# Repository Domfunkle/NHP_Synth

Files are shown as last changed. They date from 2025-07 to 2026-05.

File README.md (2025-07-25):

# NHP_Synth: ESP32 Dual DDS Synthesizer

This project implements a dual-channel Direct Digital Synthesis (DDS) signal generator on the ESP32 platform. It features:

- Two independent sine wave outputs (via DACs on GPIO25 and GPIO26)
- Precise square wave output (GPIO18) synchronized to DDS phase
- UART command interface for real-time control
- Phase, frequency, and amplitude control for each channel
- Odd harmonic mixing with amplitude and phase control per channel (total 8 simultaneous harmonics across both channels)
- External sync input (GPIO19, rising edge)
- High-resolution timer for accurate waveform generation

## Features
- **Frequency Range:** 20 Hz to 8 kHz (configurable)
- **Amplitude Ramping:** Smooth amplitude changes to prevent clicks
- **Phase Control:** Set phase offset for each channel
- **Harmonic Mixing:** Add odd harmonics (3rd, 5th, 7th, etc) to either channel, with amplitude and phase control. Up to a total of 8 harmonics can be active across both channels at once.
- **UART Commands:**
  - `wf[a|b]<freq>`: Set channel A or B frequency (Hz)
  - `wp[a|b]<deg>`: Set channel A or B phase (degrees, -180 to +180)
  - `wa[a|b]<ampl>`: Set channel A or B amplitude (0-100)
  - `wh[a|b]<order>,<pct>[,<phase>]`: Mix odd harmonic to channel A or B (e.g. `wha3,10` for 10% 3rd harmonic, or `wha7,20,-90` for 20% 7th harmonic at -90° phase)
  - `whcl[a|b]`: Clear all harmonics for channel A or B
  - `help`: Show help message

## Hardware Connections
- **DAC Channel A:** GPIO25
- **DAC Channel B:** GPIO26
- **Square Wave Output:** GPIO18
- **Sync Input:** GPIO19 (rising edge, with pulldown)

## Project Structure

```
NHP_Synth/
├── firmware/           # ESP32 firmware (ESP-IDF project)
│   ├── main/          # Main application source
│   ├── .devcontainer/ # ESP-IDF development container
│   └── .vscode/       # ESP32-specific VS Code settings
├── host/              # Python host control interface
│   ├── synth_control/ # Python control library
│   ├── examples/      # Usage examples
│   ├── .devcontainer/ # Python development container
│   └── .vscode/       # Python-specific VS Code settings
├── tools/             # Shared utilities and scripts
└── .vscode/           # Root workspace configuration
```

## Build & Flash

### Firmware (ESP32)
Navigate to the firmware directory and use ESP-IDF:

```bash
cd firmware
idf.py build
idf.py -p /dev/ttyUSB0 flash
```

Or use the convenient script for multiple devices:

```bash
./tools/flash_multiple.sh
```

## Host Control (Python)

A Python interface is provided for programmatic control:

```bash
cd host
python3 -m venv .venv
source .venv/bin/activate
pip install -r requirements.txt

# Run examples
python examples/basic_control.py
python examples/harmonic_sweep.py
```

## UART Usage
Connect to the ESP32 UART (default 115200 baud) and type commands as described above. Type `help` for a list of commands.

## Linux commands to test UART
```bash
# Generate a square wave on Channel A at 50Hz
printf "wha3,33\r" > /dev/ttyUSB1
printf "wha5,20\r" > /dev/ttyUSB1
printf "wha7,14\r" > /dev/ttyUSB1
printf "wha9,11\r" > /dev/ttyUSB1
printf "wha11,9\r" > /dev/ttyUSB1
printf "wha13,8\r" > /dev/ttyUSB1
printf "wha15,7\r" > /dev/ttyUSB1
printf "wha17,6\r" > /dev/ttyUSB1
```

```bash
# Clear all harmonics for Channel A and B
printf "whcla\r" > /dev/ttyUSB1
printf "whclb\r" > /dev/ttyUSB1
```

```bash
# Rolling harmonic phase for Channel A and B
ph=-180
while true; do
    printf "wha5,20,%d\n" "$ph" > /dev/ttyUSB1
    invph=$((ph * -1))
    printf "whb3,10,%d\n" "$invph" > /dev/ttyUSB1
    sleep 0.03
    ph=$((ph + 1))
    if [ "$ph" -gt 180 ]; then
        ph=-180
    fi
done
```

## Development

### VS Code Workspace
Open the multi-root workspace for unified development:
```bash
code .vscode/NHP_Synth.code-workspace
```

### DevContainers
Each component has its own development container:
- **Firmware**: ESP-IDF container with all tools
- **Host**: Python container with analysis libraries

### Tools
- `tools/flash_multiple.sh` - Flash firmware to multiple devices
- `tools/uart_test.py` - Test UART communication

## File Structure
- `firmware/main/main.c`: Main ESP32 application source
- `firmware/build/`: Build artifacts (ignored by git)
- `host/synth_control/`: Python control library
- `host/examples/`: Python usage examples
- `tools/`: Shared utilities and scripts
- `.gitignore`: Excludes build and config files from version control

## License
MIT License (or specify your license here)

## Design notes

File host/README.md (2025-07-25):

# NHP_Synth Host Control

Python interface for controlling the ESP32 NHP_Synth dual-channel DDS synthesizer.

## Installation

1. Create and activate a virtual environment:
```bash
python3 -m venv .venv
source .venv/bin/activate  # On Windows: .venv\Scripts\activate
```

2. Install dependencies:
```bash
pip install -r requirements.txt
```

3. Install the package in development mode:
```bash
pip install -e .
```

## Usage

### Basic Control

```python
from synth_control import SynthInterface

with SynthInterface('/dev/ttyUSB0') as synth:
    # Set frequency and amplitude
    synth.set_frequency('a', 440)  # Channel A to 440Hz
    synth.set_amplitude('a', 80)   # 80% amplitude
    
    # Add harmonics
    synth.add_harmonic('a', 3, 20)  # 3rd harmonic at 20%
    synth.add_harmonic('a', 5, 10)  # 5th harmonic at 10%
```

### Waveform Generation

```python
from synth_control import SynthInterface, WaveformGenerator

with SynthInterface('/dev/ttyUSB0') as synth:
    waveform_gen = WaveformGenerator(synth)
    
    # Generate square wave approximation
    waveform_gen.apply_waveform('a', 'square', 200, 70)
    
    # Frequency sweep
    waveform_gen.sweep_frequency('a', 100, 1000, 5)
```

## Examples

Run the example scripts:

```bash
# Basic control demo
python examples/basic_control.py

# Harmonic and waveform demonstrations
python examples/harmonic_sweep.py
```

## API Reference

### SynthInterface

- `set_frequency(channel, frequency)` - Set channel frequency (20-8000 Hz)
- `set_amplitude(channel, amplitude)` - Set channel amplitude (0-100%)
- `set_phase(channel, phase)` - Set channel phase (-180 to +180 degrees)
- `add_harmonic(channel, order, percent, phase=0)` - Add harmonic to channel
- `clear_harmonics(channel)` - Clear all harmonics from channel

### WaveformGenerator

- `apply_waveform(channel, type, frequency, amplitude)` - Apply predefined waveform
- `sweep_frequency(channel, start, end, duration)` - Perform frequency sweep
- `phase_sweep(channel, harmonic_order, duration)` - Sweep harmonic phase

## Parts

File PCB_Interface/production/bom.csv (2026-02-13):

Designator | Footprint | Quantity | Value | LCSC Part #
C1, C12, C2, C5, C6 | 0603 | 5 | 100n
C10, C9 | 0603 | 2 | 470p
C11, C13, C20, C21, C22, C24 | 0805 | 6 | 22u/16V
C14, C15 | 0603 | 2 | 22p
C16 | 0603 | 1 | 10n
C17 | 0603 | 1 | 4n7
C18, C23 | 0603 | 2 | 15p
C19 | 0603 | 1 | 220n
C3, C4 | 0603 | 2 | 10u
C7, C8 | 0603 | 2 | 1n
CN1 | CONN-TH_WJ15EDGRC-3.81-6P | 1 | WJ15EDGRC-3.81-6P | C7246
D1, D5 | SOD-123_L2.8-W1.8-LS3.7-RD | 2 | MBR120LSF | C130880
D3, D4 | SOD-123FL_L2.7-W1.8-LS3.8-BI | 2 | SMF9.0CA_C19077504 | C19077504
E1, E2 | SOD-323_L1.8-W1.3-LS2.5-RD | 2 | CESD3V3D3 | C38388
L1, L2 | IND-SMD_L5.4-W5.2_FXL0530 | 2 | 4u7 | C177246
LED1 | LED0805-R-RD | 1 | GREEN | C2297
LED2, LED3 | LED0805-R-RD | 2 | RED | C84256
Q1 | SOT-23_L2.9-W1.3-P1.90-LS2.4-BR | 1 | AO3401A | C15127
R1, R11, R12, R2, R22, R3, R4 | 0603 | 7 | 10k
R10, R7, R8, R9 | 0603 | 4 | 100k
R13, R14 | 0603 | 2 | 22k
R15 | 0603 | 1 | 100
R16, R24, R29, R5, R6 | 0603 | 5 | 47k
R17, R18, R19, R20 | 0603 | 4 | 330
R21 | 0603 | 1 | 560k
R23, R30 | 0603 | 2 | 4k7
R25 | 0603 | 1 | 59k
R26, R27 | RES-ADJ-SMD_TC33X-2-104E | 2 | 100k | C719186
R28 | 0603 | 1 | 750k
RV1, RV2 | RES-ADJ-TH_3296P | 2 | 100k | C780112
U10, U11 | HDR-TH_20P-P2.54-V-F | 2 | ZX-PM2.54-1-20PY | C7499336
U3, U4 | SOIC-14_L8.7-W3.9-P1.27-LS6.0-BL | 2 | LM324DT | C71035
U9 | QFN-24_L4.0-W4.0-P0.50-TL-EP2.6 | 1 | TPS65131RGER | C87663

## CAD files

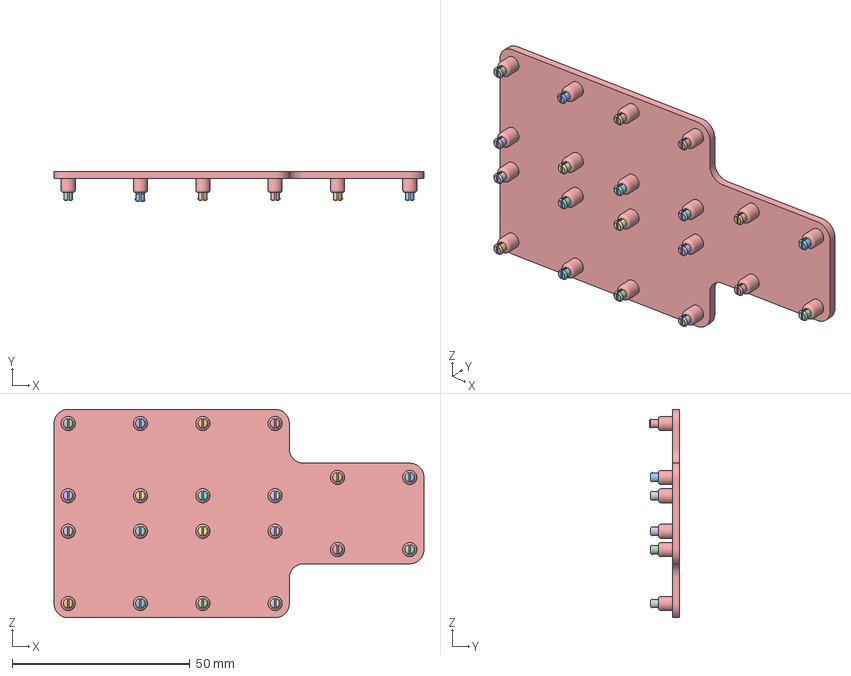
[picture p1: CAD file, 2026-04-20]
model/3-phase-synth-model-Encoder-Plate.3mf
104.1 x 8.50 x 58.6 mm

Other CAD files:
Drawing1.dwg
model/model.FCStd

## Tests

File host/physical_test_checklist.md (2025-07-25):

# NHP_Synth Physical Test Checklist

Use this checklist to verify hardware/software integration after any code changes:

## 1. Encoder Detection Test
- Power on and verify all rotary encoders are detected and initialized correctly.

## 2. Button Press Test
- Short press each encoder button and confirm mode switching (individual/all synths, channel cycling).
- Long press each encoder button and confirm reset to default values for amplitude, frequency, phase, and harmonics.

## 3. Encoder Rotation Test
- Rotate each encoder and verify amplitude, frequency, phase, and harmonics values change as expected.
- Check for correct value limits (e.g., amplitude 0–100%, frequency 20–70Hz, phase -360° to +360°).

## 4. LED Feedback Test
- Confirm LEDs respond to button presses and resets (e.g., flash white on reset, show correct color for each function).

## 5. Synth Output Test
- Measure output signals from each synth channel to verify amplitude, frequency, phase, and harmonics changes are reflected in the hardware.

## 6. State Persistence Test
- Power cycle the system and confirm synth state is saved and restored correctly.

## 7. Error Handling Test
- Disconnect one or more encoders and verify the system handles missing devices gracefully (no crash, correct status messages).

## 8. Multi-Synth Coordination Test
- Test “all synths” mode to ensure simultaneous updates across all devices.

## 9. Timeout Reversion Test
- Leave the system in “individual” mode and confirm it reverts to “all” mode after the timeout period.

## 10. Shutdown Test
- Trigger a clean shutdown and verify all synth outputs are set to zero.

---
Perform these tests after any code changes to ensure full functionality and hardware safety.

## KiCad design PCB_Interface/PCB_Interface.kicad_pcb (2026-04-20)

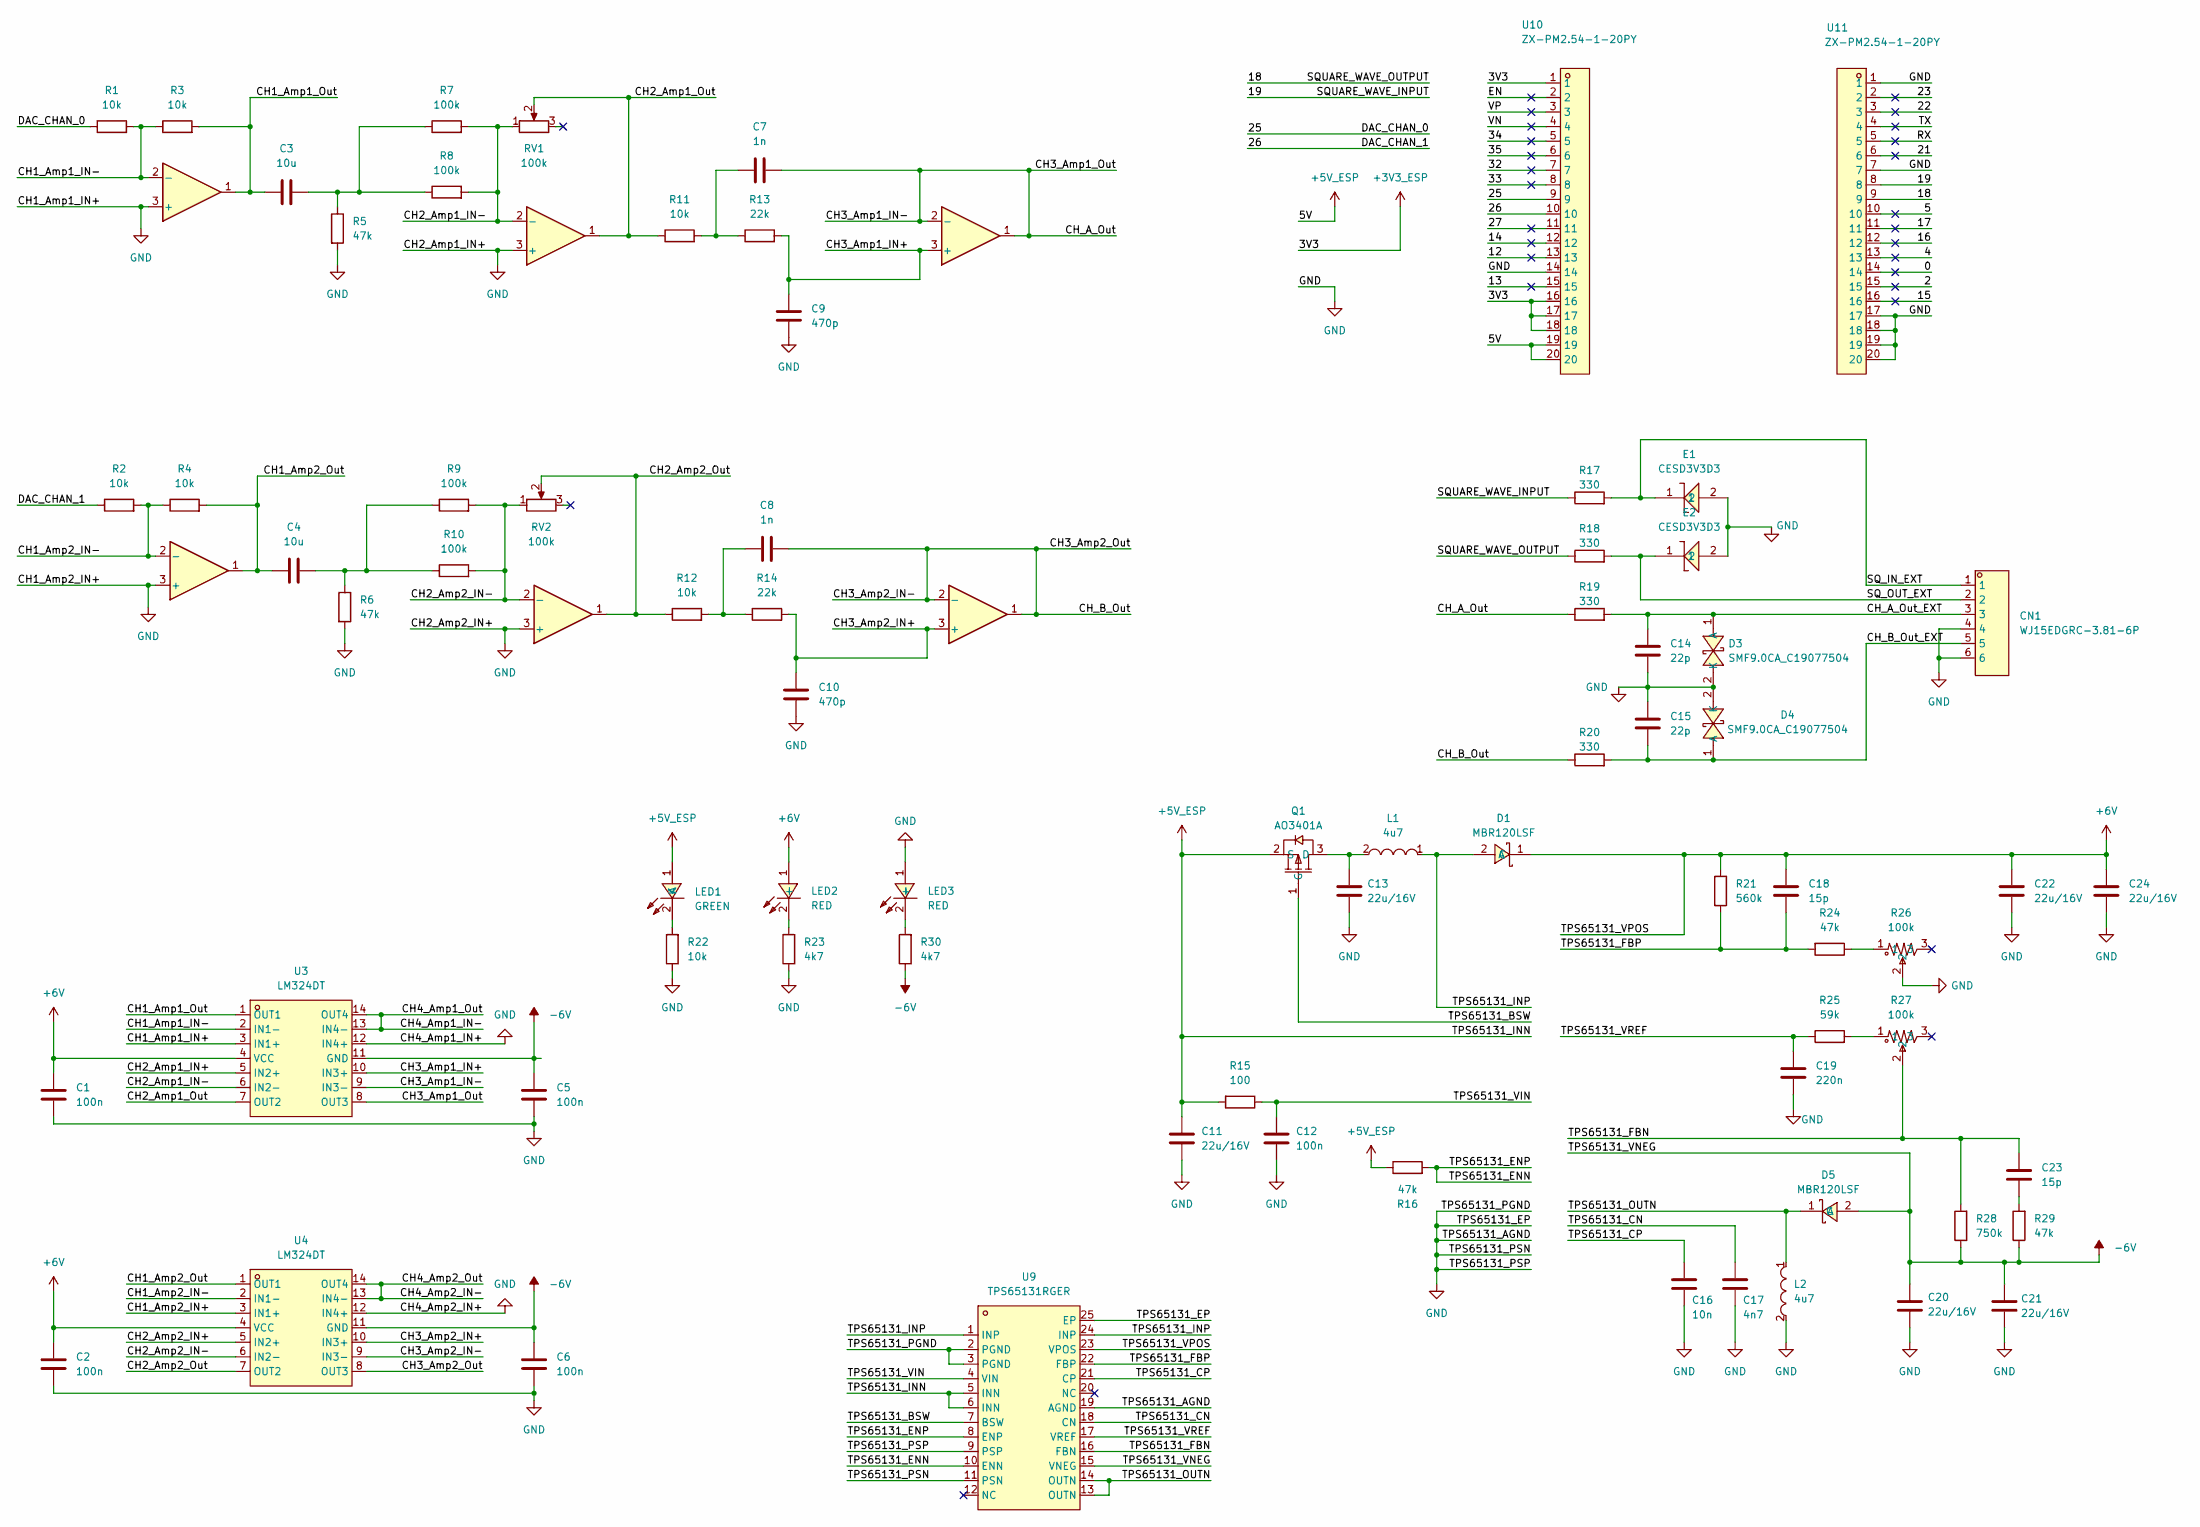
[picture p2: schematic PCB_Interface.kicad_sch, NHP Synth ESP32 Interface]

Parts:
C1, C2, C5, C6, C12: 100n; C_0603_1608Metric
C3, C4: 10u; C_0603_1608Metric
C7, C8: 1n; C_0603_1608Metric
C9, C10: 470p; C_0603_1608Metric
C11, C13, C20, C21, C22, C24: 22u/16V; C_0805_2012Metric
C14, C15: 22p; C_0603_1608Metric
C16: 10n; C_0603_1608Metric
C17: 4n7; C_0603_1608Metric
C18, C23: 15p; C_0603_1608Metric
C19: 220n; C_0603_1608Metric
CN1: WJ15EDGRC-3.81-6P; CONN-TH_WJ15EDGRC-3.81-6P; LCSC Part C7246
D1, D5: MBR120LSF; SOD-123_L2.8-W1.8-LS3.7-RD; LCSC Part C130880
D3, D4: SMF9.0CA_C19077504; SOD-123FL_L2.7-W1.8-LS3.8-BI; LCSC Part C19077504
E1, E2: CESD3V3D3; SOD-323_L1.8-W1.3-LS2.5-RD; LCSC Part C38388
L1, L2: 4u7; IND-SMD_L5.4-W5.2_FXL0530; LCSC Part C177246
LED1: GREEN; LED0805-R-RD; LCSC Part C2297
LED2, LED3: RED; LED0805-R-RD; LCSC Part C84256
Q1: AO3401A; SOT-23_L2.9-W1.3-P1.90-LS2.4-BR; LCSC Part C15127
R1, R2, R3, R4, R11, R12, R22: 10k; R_0603_1608Metric
R5, R6, R16, R24, R29: 47k; R_0603_1608Metric
R7, R8, R9, R10: 100k; R_0603_1608Metric
R13, R14: 22k; R_0603_1608Metric
R15: 100; R_0603_1608Metric
R17, R18, R19, R20: 330; R_0603_1608Metric
R21: 560k; R_0603_1608Metric
R23, R30: 4k7; R_0603_1608Metric
R25: 59k; R_0603_1608Metric
R26, R27: 100k; RES-ADJ-SMD_TC33X-2-104E; LCSC Part C719186
R28: 750k; R_0603_1608Metric
RV1, RV2: 100k; RES-ADJ-TH_3296P; LCSC Part C780112
U1, U2, U5, U6, U7, U8: LM324
U3, U4: LM324DT; SOIC-14_L8.7-W3.9-P1.27-LS6.0-BL; LCSC Part C71035
U9: TPS65131RGER; QFN-24_L4.0-W4.0-P0.50-TL-EP2.6; LCSC Part C87663
U10, U11: ZX-PM2.54-1-20PY; HDR-TH_20P-P2.54-V-F; LCSC Part C7499336

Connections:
+3V3_ESP: U10.1, U10.16, U10.17, U10.18
+5V_ESP: C11.1, LED1.1 (A), Q1.2 (S), R15.2, R16.1, U9.5 (INN), U9.6 (INN), U10.19, U10.20
+6V: C1.2, C2.2, C18.1, C22.1, C24.1, D1.1 (C), LED2.1 (+), R21.2, U3.4 (VCC), U4.4 (VCC), U9.23 (VPOS)
-6V: C5.2, C6.2, C20.1, C21.1, D5.2 (A), R28.1, R29.1, R30.1, U3.11 (GND), U4.11 (GND), U9.15 (VNEG)
/0: U11.14
/2: U11.15
/4: U11.13
/5: U11.10
/12: U10.13
/13: U10.15
/14: U10.12
/15: U11.16
/16: U11.12
/17: U11.11
/18: R18.1, U11.9
/19: R17.1, U11.8
/21: U11.6
/22: U11.3
/23: U11.2
/25: R1.1, U10.9
/26: R2.1, U10.10
/27: U10.11
/32: U10.7
/33: U10.8
/34: U10.5
/35: U10.6
/CH1_Amp1_IN-: R1.2, R3.1, U1.2 (-), U3.2 (IN1-)
/CH1_Amp1_Out: C3.1, R3.2, U1.1, U3.1 (OUT1)
/CH1_Amp2_IN-: R2.2, R4.1, U2.2 (-), U4.2 (IN1-)
/CH1_Amp2_Out: C4.1, R4.2, U2.1, U4.1 (OUT1)
/CH2_Amp1_IN-: R7.2, R8.2, RV1.1, U3.6 (IN2-), U5.2 (-)
/CH2_Amp1_Out: R11.1, RV1.2, U3.7 (OUT2), U5.1
/CH2_Amp2_IN-: R9.2, R10.2, RV2.1, U4.6 (IN2-), U6.2 (-)
/CH2_Amp2_Out: R12.1, RV2.2, U4.7 (OUT2), U6.1
/CH3_Amp1_IN+: C9.2, R13.2, U3.10 (IN3+), U7.3 (+)
/CH3_Amp1_IN-: C7.2, R19.1, U3.8 (OUT3), U3.9 (IN3-), U7.1, U7.2 (-)
/CH3_Amp2_IN+: C10.2, R14.2, U4.10 (IN3+), U8.3 (+)
/CH3_Amp2_IN-: C8.2, R20.1, U4.8 (OUT3), U4.9 (IN3-), U8.1, U8.2 (-)
/CH4_Amp1_IN-: U3.13 (IN4-), U3.14 (OUT4)
/CH4_Amp2_IN-: U4.13 (IN4-), U4.14 (OUT4)
/CH_A_Out_EXT: C14.1, CN1.3, D3.1 (A), R19.2
/CH_B_Out_EXT: C15.2, CN1.5, D4.1 (A), R20.2
/EN: U10.2
/RX: U11.5
/SQ_IN_EXT: CN1.1, E1.1, R17.2
/SQ_OUT_EXT: CN1.2, E2.1, R18.2
/TPS65131_BSW: Q1.1 (G), U9.7 (BSW)
/TPS65131_CN: C17.1, U9.18 (CN)
/TPS65131_CP: C16.1, U9.21 (CP)
/TPS65131_ENN: R16.2, U9.8 (ENP), U9.10 (ENN)
/TPS65131_FBN: C23.1, R27.2, R28.2, U9.16 (FBN)
/TPS65131_FBP: C18.2, R21.1, R24.2, U9.22 (FBP)
/TPS65131_INP: D1.2 (A), L1.1, U9.1 (INP), U9.24 (INP)
/TPS65131_OUTN: D5.1 (C), L2.1, U9.13 (OUTN), U9.14 (OUTN)
/TPS65131_VIN: C12.1, R15.1, U9.4 (VIN)
/TPS65131_VREF: C19.1, R25.1, U9.17 (VREF)
/TX: U11.4
/VN: U10.4
/VP: U10.3
GND: C1.1, C2.1, C5.1, C6.1, C9.1, C10.1, C11.2, C12.2, C13.2, C14.2, C15.1, C16.2, C17.2, C19.2, C20.2, C21.2, C22.2, C24.2, CN1.4, CN1.6, D3.2 (K), D4.2 (K), E1.2, E2.2, L2.2, LED3.1 (+), R5.2, R6.2, R22.1, R23.1, R26.2, U1.3 (+), U2.3 (+), U3.3 (IN1+), U3.5 (IN2+), U3.12 (IN4+), U4.3 (IN1+), U4.5 (IN2+), U4.12 (IN4+), U5.3 (+), U6.3 (+), U9.2 (PGND), U9.3 (PGND), U9.9 (PSP), U9.11 (PSN), U9.19 (AGND), U9.25 (EP), U10.14, U11.1, U11.7, U11.17, U11.18, U11.19, U11.20
unnamed: C3.2, R5.1, R7.1, R8.1
unnamed: C4.2, R6.1, R9.1, R10.1
unnamed: C7.1, R11.2, R13.1
unnamed: C8.1, R12.2, R14.1
unnamed: C23.2, R29.2
unnamed: LED1.2 (K), R22.2
unnamed: LED2.2 (-), R23.2
unnamed: LED3.2 (-), R30.2
unnamed: C13.1, L1.2, Q1.3 (D)
unnamed: R24.1, R26.1
unnamed: R25.2, R27.1

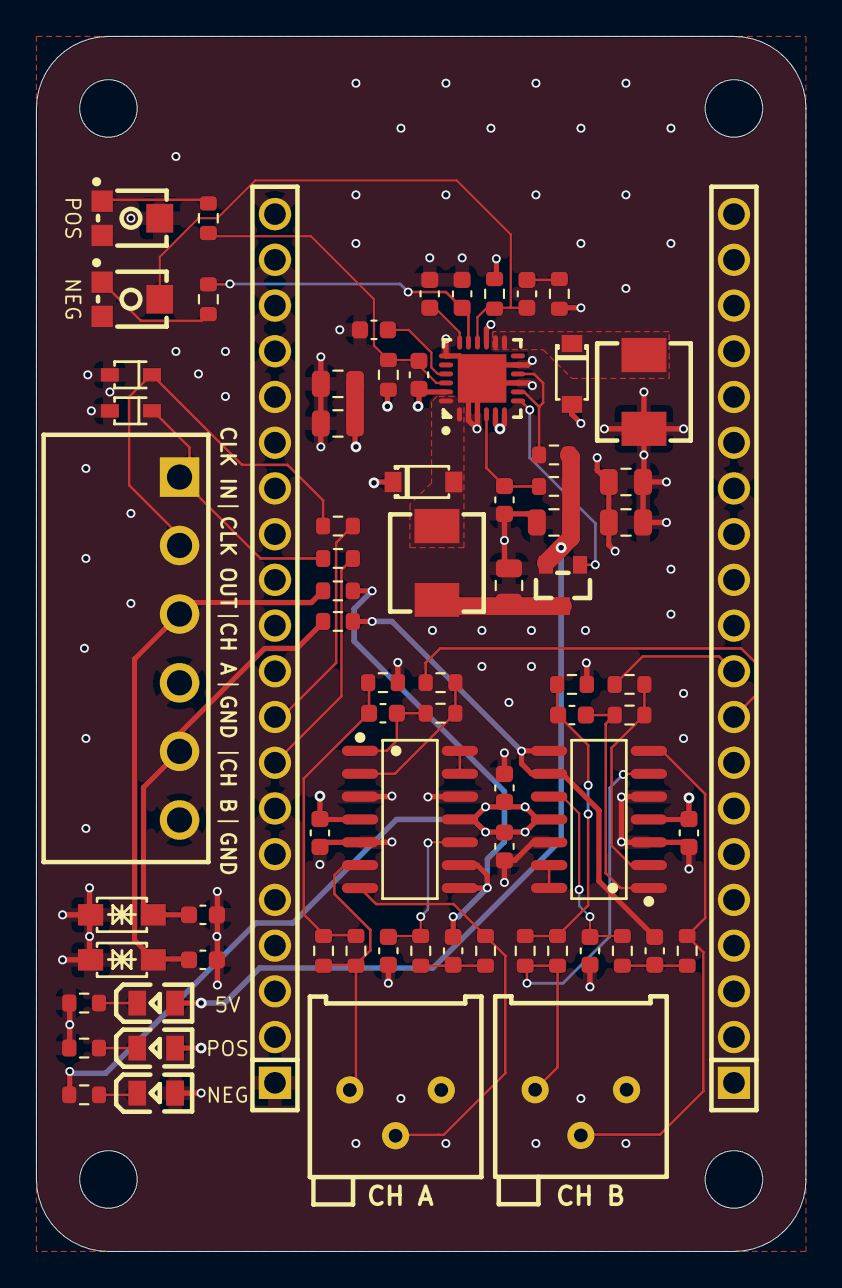
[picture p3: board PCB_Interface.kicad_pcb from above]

Board: 4 copper layers, 42.8 x 67.5 mm, 74 parts (0 on the bottom side), 48 nets.

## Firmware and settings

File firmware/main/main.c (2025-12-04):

// Includes
#include <stdio.h>
#include <math.h>
#include <string.h>
#include "freertos/FreeRTOS.h"
#include "freertos/task.h"
#include "esp_log.h"
#include "esp_timer.h"
#include "driver/uart.h"
#include "driver/gpio.h"
#include "esp_task_wdt.h"
#include "driver/dac_oneshot.h"

// Macros and Constants
#define TABLE_SIZE (1 << 16)
#define MIN_FREQ 20
#define MAX_FREQ 8000
#define UART_NUM UART_NUM_0
#define UART_RX_BUF_SIZE 256
#define SQUARE_WAVE_OUTPUT 18  // GPIO for square wave output
#define SQUARE_WAVE_INPUT 19
#define SQUARE_WAVE_HZ 50
#define PERIOD_US 50         // period in microseconds for DDS output
#define AMPL_RAMP_STEP 1e-3 // Adjust for ramp speed (smaller = slower)
#define MAX_HARMONICS 8 // Maximum harmonics across both channels
#define PHASE_SCALE (int)(TABLE_SIZE / (2.0 * M_PI))
#define M_PI_180 (M_PI / 180.0f)

// Per-channel harmonics (arrays for multiple harmonics)
typedef struct {
    int order;
    float percent; // 0-100
    float phase;   // radians
    int phase_offset_int; // cached phase offset for DDS
} harmonic_t;

static volatile harmonic_t harmonics[2][MAX_HARMONICS] = {{{0}}};

// Static Variables
static const char *TAG = "dac_oneshot_test";
static uint8_t waveform_quarter_table[TABLE_SIZE / 4]; // Store only a quarter of the waveform table to save memory

// Per-channel frequency, phase, amplitude, harmonic
static volatile float current_freq[2] = {50, 50}; // [A, B]
static volatile float current_phase[2] = {0, 0};
static volatile float current_ampl[2] = {0.0f, 0.0f}; // Used for output (ramped)
static volatile float target_ampl[2] = {0.0f, 0.0f}; // Set by UART, ramped to
static volatile bool enable_output[2] = {false, false}; // Per-channel DAC output enable/disable [A, B]
static volatile float output_scale[2] = {0.0f, 0.0f}; // Per-channel output scaling for enable/disable ramping

static volatile uint32_t dds_acc[2] = {0, 0};
static volatile uint32_t dds_step[2] = {1, 1};
static volatile uint32_t dds_phase_offset[2] = {0, 0};
static volatile uint32_t sqw_acc = 0; // Accumulator for square wave generation
static volatile int sqw_output_state = 0;
static volatile int sqw_period_ticks = 0;
static volatile bool sqw_initialized = false;

// High-resolution timer handle
typedef struct {
    esp_timer_handle_t handle;
    int64_t period_us;
} highres_timer_t;

static highres_timer_t dds_timer = {0};

// DDS configuration structure
typedef struct {
    dac_oneshot_handle_t dac_handle[2];
    dac_oneshot_config_t dac_cfg[2];
} dds_config_t;

static dds_config_t dds_cfg = {
    .dac_handle = {NULL, NULL},
    .dac_cfg = {
        { .chan_id = DAC_CHAN_0 }, // GPIO25 (A)
        { .chan_id = DAC_CHAN_1 }  // GPIO26 (B)
    },
};

// Global GPIO config for square wave output
static gpio_config_t square_wave_OUTPUT_conf = {
    .pin_bit_mask = (1ULL << SQUARE_WAVE_OUTPUT),
    .mode = GPIO_MODE_OUTPUT,
    .pull_up_en = GPIO_PULLUP_DISABLE,
    .pull_down_en = GPIO_PULLDOWN_DISABLE,
    .intr_type = GPIO_INTR_DISABLE
};
// Global GPIO config for input on GPIO19 with pull-down and rising edge interrupt
#define GPIO_INPUT_PIN SQUARE_WAVE_INPUT
static gpio_config_t input_gpio_conf = {
    .pin_bit_mask = (1ULL << GPIO_INPUT_PIN),
    .mode = GPIO_MODE_INPUT,
    .pull_up_en = GPIO_PULLUP_DISABLE,
    .pull_down_en = GPIO_PULLDOWN_ENABLE,
    .intr_type = GPIO_INTR_POSEDGE
};

// Function Declarations
static void generate_waveform(int table_size);
static void update_dds_step(int ch, float frequency, float period_us);
static void uart_cmd_task(void *arg);
static void dds_output(void);
static void dds_timer_callback(void* arg);
static void start_dds_timer(int64_t period_us);
static void global_gpio_init(void);
// static void pause_dds_timer(void);
// static void resume_dds_timer(void);

// Function Definitions
static void generate_waveform(int table_size) {
    int quarter = table_size / 4;
    for (int i = 0; i < quarter; i++) {
        float phase_val = (M_PI_2 * i) / (float)quarter; // 0 to pi/2
        float val = sinf(phase_val);
        uint8_t value = (uint8_t)((val * 127.5f) + 127.5f); // 0-255 range
        waveform_quarter_table[i] = value;
    }
}
// Helper to reconstruct full sine using quarter table and symmetry
static uint8_t get_waveform_value(uint32_t idx) {
    uint32_t quarter = TABLE_SIZE / 4;
    idx = idx % TABLE_SIZE;
    if (idx < quarter) {
        // 0 to pi/2: +sin
        return waveform_quarter_table[idx];
    } else if (idx < 2 * quarter) {
        // pi/2 to pi: +sin (mirrored, inverted)
        return waveform_quarter_table[quarter - 1 - (idx - quarter)];
    } else if (idx < 3 * quarter) {
        // pi to 3pi/2: -sin
        return 255 - waveform_quarter_table[idx - 2 * quarter];
    } else {
        // 3pi/2 to 2pi: -sin (mirrored, inverted)
        return 255 - waveform_quarter_table[quarter - 1 - (idx - 3 * quarter)];
    }
}

static void update_dds_step(int ch, float frequency, float period_us) {
    dds_step[ch] = (TABLE_SIZE * frequency * period_us / 1000000);
    dds_phase_offset[ch] = (uint32_t)(current_phase[ch] * PHASE_SCALE);
    // ESP_LOGI(TAG, "DDS step and phase offset updated for channel %d: step %lu, phase offset %lu for frequency %.1f Hz", 
    //          ch, dds_step[ch], dds_phase_offset[ch], frequency);
}

static void uart_cmd_task(void *arg) {
    uart_config_t uart_config = {
        .baud_rate = 115200,
        .data_bits = UART_DATA_8_BITS,
        .parity    = UART_PARITY_DISABLE,
        .stop_bits = UART_STOP_BITS_1,
        .flow_ctrl = UART_HW_FLOWCTRL_DISABLE
    };
    esp_err_t err = uart_driver_install(UART_NUM, UART_RX_BUF_SIZE, 0, 0, NULL, 0);
    if (err != ESP_OK) {
        ESP_LOGE(TAG, "uart_driver_install failed: %d", err);
        vTaskDelete(NULL);
    }
    uart_param_config(UART_NUM, &uart_config);
    uart_set_pin(UART_NUM, UART_PIN_NO_CHANGE, UART_PIN_NO_CHANGE, UART_PIN_NO_CHANGE, UART_PIN_NO_CHANGE);
    // ESP_LOGI(TAG, "UART command task started. Type 'help' for usage.");
    char cmd_buf[32];
    int cmd_pos = 0;
    while (1) {
        uint8_t ch;
        int len = uart_read_bytes(UART_NUM, &ch, 1, pdMS_TO_TICKS(100));
        if (len > 0) {
            if (ch == '\r' || ch == '\n') {
                cmd_buf[cmd_pos] = '\0';
                // Unified frequency read command: rfa / rfb
                if (strncmp(cmd_buf, "rf", 2) == 0 && (cmd_buf[2] == 'a' || cmd_buf[2] == 'b')) {
                    int ch_idx = (cmd_buf[2] == 'a') ? 0 : 1;
                    char response[32];
                    snprintf(response, sizeof(response), "rf%c%.1f\r\n", 
                             ch_idx == 0 ? 'a' : 'b', current_freq[ch_idx]);
                    uart_write_bytes(UART_NUM, response, strlen(response));
                
                // Unified frequency write command: wfa / wfb
                } else if (strncmp(cmd_buf, "wf", 2) == 0 && (cmd_buf[2] == 'a' || cmd_buf[2] == 'b')) {
                    int ch_idx = (cmd_buf[2] == 'a') ? 0 : 1;
                    float freq = strtof(cmd_buf + 3, NULL);
                    if (freq >= MIN_FREQ && freq <= MAX_FREQ) {
                        current_freq[ch_idx] = freq;
                        update_dds_step(ch_idx, current_freq[ch_idx], PERIOD_US);
                        // ESP_LOGI(TAG, "UART: Set channel %c frequency to %.1f Hz", ch_idx == 0 ? 'A' : 'B', freq);
                    } else {
                        ESP_LOGW(TAG, "UART: Invalid channel %c frequency: %.1f (Allowed: %d-%d)", ch_idx == 0 ? 'A' : 'B', freq, MIN_FREQ, MAX_FREQ);
                    }

                // Unified phase read command: rpa / rpb
                } else if (strncmp(cmd_buf, "rp", 2) == 0 && (cmd_buf[2] == 'a' || cmd_buf[2] == 'b')) {
                    int ch_idx = (cmd_buf[2] == 'a') ? 0 : 1;
                    char response[32];
                    snprintf(response, sizeof(response), "rp%c%.1f\r\n", 
                             ch_idx == 0 ? 'a' : 'b', current_phase[ch_idx] * 180.0f / M_PI);
                    uart_write_bytes(UART_NUM, response, strlen(response));

                // Unified phase write command: wpa / wpb
                } else if (strncmp(cmd_buf, "wp", 2) == 0 && (cmd_buf[2] == 'a' || cmd_buf[2] == 'b')) {
                    int ch_idx = (cmd_buf[2] == 'a') ? 0 : 1;
                    float phase = strtof(cmd_buf + 3, NULL);
                    if (phase < -360.0f || phase > 360.0f) {
                        ESP_LOGW(TAG, "UART: Invalid channel %c phase: %f (Allowed: -360 to +360)", ch_idx == 0 ? 'A' : 'B', phase);
                    }
                    if (phase < -360.0f) phase = -360.0f;
                    if (phase > 360.0f) phase = 360.0f;
                    current_phase[ch_idx] = phase * M_PI_180;
                    // ESP_LOGI(TAG, "UART: Set channel %c phase to %f degrees (%.2f radians)", ch_idx == 0 ? 'A' : 'B', phase, current_phase[ch_idx]);
                
                // Unified amplitude read command: raa / rab
                } else if (strncmp(cmd_buf, "ra", 2) == 0 && (cmd_buf[2] == 'a' || cmd_buf[2] == 'b')) {
                    int ch_idx = (cmd_buf[2] == 'a') ? 0 : 1;
                    char response[32];
                    snprintf(response, sizeof(response), "ra%c%.1f\r\n", 
                             ch_idx == 0 ? 'a' : 'b', current_ampl[ch_idx] * 100.0f);
                    uart_write_bytes(UART_NUM, response, strlen(response));

                    // Unified amplitude write command: waa / wab
                } else if (strncmp(cmd_buf, "wa", 2) == 0 && (cmd_buf[2] == 'a' || cmd_buf[2] == 'b')) {
                    int ch_idx = (cmd_buf[2] == 'a') ? 0 : 1;
                    float ampl = strtof(cmd_buf + 3, NULL);
                    if (ampl < 0.0f) ampl = 0.0f;
                    if (ampl > 100.0f) ampl = 100.0f;
                    target_ampl[ch_idx] = ampl / 100.0f;
                    // ESP_LOGI(TAG, "UART: Set channel %c amplitude to %.2f (0-100, scaled to 0.0-1.0)", ch_idx == 0 ? 'A' : 'B', ampl);

                // Read output enable state: rena / renb
                } else if (strncmp(cmd_buf, "ren", 3) == 0 && (cmd_buf[3] == 'a' || cmd_buf[3] == 'b')) {
                    int ch_idx = (cmd_buf[3] == 'a') ? 0 : 1;
                    char response[32];
                    snprintf(response, sizeof(response), "ren%c%d\r\n", 
                             ch_idx == 0 ? 'a' : 'b', enable_output[ch_idx] ? 1 : 0);
                    uart_write_bytes(UART_NUM, response, strlen(response));

                // Write output enable state: wena0/wena1 or wenb0/wenb1
                } else if (strncmp(cmd_buf, "wen", 3) == 0 && (cmd_buf[3] == 'a' || cmd_buf[3] == 'b')) {
                    int ch_idx = (cmd_buf[3] == 'a') ? 0 : 1;
                    int enable = strtol(cmd_buf + 4, NULL, 10);
                    enable_output[ch_idx] = (enable != 0);
                    // ESP_LOGI(TAG, "UART: Set channel %c output enable to %s", ch_idx == 0 ? 'A' : 'B', enable_output[ch_idx] ? "true" : "false");

                // Shortcut: clear all harmonics for a channel (must come before wh[a|b] command)
                } else if ((strncmp(cmd_buf, "whcl", 4) == 0 && cmd_buf[4] == 'a') ||
                           (strncmp(cmd_buf, "whcl", 4) == 0 && cmd_buf[4] == 'b')) {
                    int ch_idx = (cmd_buf[4] == 'a') ? 0 : 1;
                    for (int i = 0; i < MAX_HARMONICS; ++i) {
                        harmonics[ch_idx][i].order = 0;
                        harmonics[ch_idx][i].percent = 0.0f;
                        harmonics[ch_idx][i].phase = 0.0f;
                    }
                    // ESP_LOGI(TAG, "UART: Cleared all harmonics for channel %c", ch_idx == 0 ? 'A' : 'B');

                // Unified harmonic read command: rha / rhb
                } else if (strncmp(cmd_buf, "rh", 2) == 0 && (cmd_buf[2] == 'a' || cmd_buf[2] == 'b')) {
                    int ch_idx = (cmd_buf[2] == 'a') ? 0 : 1;
                    char response[256];
                    snprintf(response, sizeof(response), "rh%c", ch_idx == 0 ? 'a' : 'b');
                    for (int i = 0; i < MAX_HARMONICS; ++i) {
                        if (harmonics[ch_idx][i].order >= 3 && harmonics[ch_idx][i].percent > 0.0f) {
                            snprintf(response + strlen(response), sizeof(response) - strlen(response),
                                     "%d,%.1f,%.1f;", harmonics[ch_idx][i].order,
                                     harmonics[ch_idx][i].percent * 100.0f,
                                     harmonics[ch_idx][i].phase * 180.0f / M_PI);
                        }
                    }
                    strcat(response, "\r\n");
                    uart_write_bytes(UART_NUM, response, strlen(response));

                // Unified harmonic write command: wha / whb
                } else if (strncmp(cmd_buf, "wh", 2) == 0 && (cmd_buf[2] == 'a' || cmd_buf[2] == 'b')) {
                    int ch_idx = (cmd_buf[2] == 'a') ? 0 : 1;
                    int order = 0;
                    float percent = 0.0f;
                    float phase_deg = 0.0f;
                    char *comma = strchr(cmd_buf + 3, ',');
                    if (comma) {
                        order = strtol(cmd_buf + 3, NULL, 10);
                        percent = strtof(comma + 1, NULL);
                        char *comma2 = strchr(comma + 1, ',');
                        if (comma2) {
                            phase_deg = strtof(comma2 + 1, NULL);
                        }
                        if (order < 3 || (order % 2) == 0) {
                            ESP_LOGW(TAG, "UART: Harmonic order must be odd and >= 3");
                        } else if (percent < 0.0f || percent > 100.0f) {
                            ESP_LOGW(TAG, "UART: Harmonic percent must be 0-100");
                        } else {
                            // Count total harmonics in use globally
                            int total_harmonics = 0;
                            for (int c = 0; c < 2; ++c) {
                                for (int i = 0; i < MAX_HARMONICS; ++i) {
                                    if (harmonics[c][i].order >= 3 && harmonics[c][i].percent > 0.0f) {
                                        total_harmonics++;
                                    }
                                }
                            }
                            // Add or update harmonic for this channel
                            int found = 0;
                            for (int i = 0; i < MAX_HARMONICS; ++i) {
                                if (harmonics[ch_idx][i].order == order) {
                                    harmonics[ch_idx][i].percent = percent / 100.0f;
                                    harmonics[ch_idx][i].phase = phase_deg * M_PI_180;
                                    harmonics[ch_idx][i].phase_offset_int = (int)(harmonics[ch_idx][i].phase * PHASE_SCALE);
                                    found = 1;
                                    break;
                                }
                            }
                            if (!found && percent > 0.0f) {
                                if (total_harmonics < MAX_HARMONICS) {
                                    for (int i = 0; i < MAX_HARMONICS; ++i) {
                                        if (harmonics[ch_idx][i].order == 0 || harmonics[ch_idx][i].percent == 0.0f) {
                                            harmonics[ch_idx][i].order = order;
                                            harmonics[ch_idx][i].percent = percent / 100.0f;
                                            harmonics[ch_idx][i].phase = phase_deg * M_PI_180;
                                            harmonics[ch_idx][i].phase_offset_int = (int)(harmonics[ch_idx][i].phase * PHASE_SCALE);
                                            found = 1;
                                            break;
                                        }
                                    }
                                } else {
                                    ESP_LOGW(TAG, "UART: Max harmonics reached globally");
                                }
                            }
                            // If percent is 0, the harmonic is disabled (kept in list but ignored)
                        }
                    } else {
                        ESP_LOGW(TAG, "UART: Invalid harmonic command format. Use e.g. wha3,10 or wha3,10,-90");
                    }
                } else if (strcmp(cmd_buf, "help") == 0) {
                    const char *help_msg =
                        "Command: [r|w][f|p|a|h|en][a|b][<args>]\r\n"
                        "  r=read, w=write; f=frequency, p=phase, a=amplitude, h=harmonic, en=enable\r\n"
                        "  a=ch A, b=ch B; <args>=value(s) for write\r\n"
                        "\r\n"
                        "Harmonic: wh[a|b]<n>,<percent>[,<phase_deg>]\r\n"
                        "  n=odd harmonic (>=3), percent=0-100, phase_deg=deg (optional)\r\n"
                        "Special:\r\n"
                        "  whcl[a|b]   Clear all harmonics for A/B\r\n"
                        "  ren[a|b]    Read output enable state for A/B (0=disabled, 1=enabled)\r\n"
                        "  wen[a|b][0|1] Write output enable state for A/B (0=disable, 1=enable)\r\n"
                        "  help        Show this help\r\n"
                        "\r\n"
                        "Examples:\r\n"
                        "  rfa         Read freq A (ex. response rfa50.0 = 50.0 Hz)\r\n"
                        "  wfb45.5     Set freq B to 45.5 Hz\r\n"
                        "  rpa         Read phase A (ex. response rpa-120.0 = -120.0 deg)\r\n"
                        "  wpa-90      Set phase A to -90 deg\r\n"
                        "  rab         Read amp B (ex. response rab55.0 = 55.0 %)\r\n"
                        "  waa50       Set amp A to 50%\r\n"
                        "  rena        Read enable state A (ex. response rena1 = enabled)\r\n"
                        "  wena0       Disable DAC output A\r\n"
                        "  wenb1       Enable DAC output B\r\n"
                        "  rha         Read harmonics A (ex. response rha3,10.0,0.0;5,20.0,-90.0; = 3rd 10% 0 deg; 5th 20% -90 deg)\r\n"
                        "  wha3,10     Set 3rd harm A to 10%\r\n"
                        "  whb5,5,-90  Set 5th harm B to 5%, -90 deg\r\n";

                    uart_write_bytes(UART_NUM, help_msg, strlen(help_msg));
                } else if (cmd_pos > 0) {
                    ESP_LOGW(TAG, "UART: Unknown command: '%s'", cmd_buf);
                }
                cmd_pos = 0;
            } else if (cmd_pos < (int)sizeof(cmd_buf) - 1) {
                cmd_buf[cmd_pos++] = ch;
            }
        }
    }
}
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
void app_main(void) {
    generate_waveform(TABLE_SIZE);
    update_dds_step(0, current_freq[0], PERIOD_US);
    update_dds_step(1, current_freq[1], PERIOD_US);
    
    global_gpio_init();
    // ESP_LOGI(TAG, "Starting DAC DDS generator. Type 'help' in UART for usage. Frequency range: %d-%d Hz.", MIN_FREQ, MAX_FREQ);
    xTaskCreatePinnedToCore(uart_cmd_task, "uart_cmd_task", 8192, NULL, 5, NULL, 1);
    start_dds_timer(PERIOD_US);
}

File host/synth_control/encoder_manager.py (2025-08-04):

"""
EncoderManager using Encoder abstraction.
Handles button press, hold, release, rotation, and LED logic for each encoder.
"""
import time
import logging

logger = logging.getLogger("NHP_Synth")

class EncoderManager:
    def __init__(self, encoders, led_colors, state=None, hold_threshold=1.0, synth_interface=None):
        """
        :param encoders: dict mapping function names to Encoder instances
        :param led_colors: dict mapping function names to default LED colors (RGB tuples)
        :param hold_threshold: seconds to consider a button as held
        :param state: SynthStateManager instance to access synth state
        :param synth_interface: SynthInterface instance to control synths
        """
        self.encoders = encoders
        self.led_colors = led_colors
        self.short_hold_threshold = hold_threshold  # 1.0s for enable/disable toggle
        self.long_hold_threshold = 3.0  # 3.0s for reset to defaults
        self.state = state
        self.synth_interface = synth_interface
        self.button_hold_time = {k: None for k in encoders}
        self.was_short_held = {k: False for k in encoders}
        self.was_long_held = {k: False for k in encoders}
        self.selection_mode = {k: {'synth': 'all', 'ch': 'all'} for k in encoders}
        self.state.selection_mode = self.selection_mode  # Share selection mode with state manager
        self.selection_mode_last_changed = {k: time.time() for k in encoders}  # Track last change time for each func
        # LED flashing for hold indication
        self.flash_state = {k: False for k in encoders}  # Track LED on/off state during flashing
        self.last_flash_time = {k: 0 for k in encoders}  # Track last flash toggle time

    # --- Public interface ---
    def update(self):
        """Call this in your main loop to process all encoders and handle selection_mode timeout."""
        now = time.time()
        # Timeout logic for selection_mode
        for func in self.selection_mode:
            last_changed = self.selection_mode_last_changed.get(func, now)
            if now - last_changed > 60:
                if self.selection_mode[func] != {'synth': 'all', 'ch': 'all'}:
                    self.selection_mode[func] = {'synth': 'all', 'ch': 'all'}
                    self.selection_mode_last_changed[func] = now
                    logger.info(f"Selection mode for {func} timed out, reverted to all/all")
        for func, encoder in self.encoders.items():
            # Handle rotation
            delta = encoder.delta
            if delta != 0:
                self.on_rotate(func, delta)
                
            if encoder.button_pressed:
                if self.button_hold_time[func] is None:
                    self.button_hold_time[func] = now
                    self.was_short_held[func] = False
                    self.was_long_held[func] = False
                    self.flash_state[func] = False
                    self.last_flash_time[func] = now
                elif not self.was_short_held[func] and now - self.button_hold_time[func] > self.short_hold_threshold:
                    self.was_short_held[func] = True
                    # Start slow flashing for short hold indication
                    self._handle_led_flashing(func, now, flash_interval=0.1)
                elif not self.was_long_held[func] and now - self.button_hold_time[func] > self.long_hold_threshold:
                    self.was_long_held[func] = True
                    # Start fast flashing for long hold indication
                    self._handle_led_flashing(func, now, flash_interval=0.01)
                else:
                    # Handle flashing during hold periods
                    if self.was_long_held[func]:
                        self._handle_led_flashing(func, now, flash_interval=0.01)  # Fast flash
                    elif self.was_short_held[func]:
                        self._handle_led_flashing(func, now, flash_interval=0.1)  # Slow flash
            else:
                if self.button_hold_time[func] is not None:
                    if self.was_long_held[func]:
                        self.on_release_after_long_hold(func)
                    elif self.was_short_held[func]:
                        self.on_release_after_short_hold(func)
                    else:
                        self.on_press(func)
                    # Reset button state and LED
                    self.button_hold_time[func] = None
                    self.was_short_held[func] = False
                    self.was_long_held[func] = False
                    self.flash_state[func] = False
                    self.encoders[func].set_pixel(self.led_colors[func])

    def on_rotate(self, func, delta):
        """Handle rotation for each encoder based on its own selection_mode and func. Reset inactivity timer."""
        self.selection_mode_last_changed[func] = time.time()  # Reset inactivity timer on rotation
        mode = self.selection_mode.get(func, {'synth': 'all', 'ch': 'all'})
        handler_map = {
            'voltage': self._handle_voltage,
            'current': self._handle_current,
            'phase': self._handle_phase,
            'frequency': self._handle_frequency,
            'harmonics': self._handle_harmonics
        }
        handler = handler_map.get(func, self._handle_generic)
        handler(delta, mode)

    def on_press(self, func):
        """Handle short button press for each encoder: cycle selection modes for that encoder only."""
        logger.info(f"{func}: Button pressed (cycle selection mode)")
        self.selection_mode_last_changed[func] = time.time()  # Update last changed time
        self.encoders[func].set_pixel((0, 0, 255))
        time.sleep(0.1)
        self.encoders[func].set_pixel(self.led_colors[func])

        num_synths = self.state.num_synths
        channels = ['a', 'b']

        # Limit selection modes depending on the function
        if func == 'voltage':
            # Only switch between synths, always channel 'a'
            selection_modes = [{'synth': 'all', 'ch': 'a'}]
            for synth_idx in range(num_synths):
                selection_modes.append({'synth': synth_idx, 'ch': 'a'})
        elif func == 'current':
            # Only switch between synths, always channel 'b'
            selection_modes = [{'synth': 'all', 'ch': 'b'}]
            for synth_idx in range(num_synths):
                selection_modes.append({'synth': synth_idx, 'ch': 'b'})
        elif func == 'frequency':
            # dont switch anything, leave as all/all
            selection_modes = [{'synth': 'all', 'ch': 'all'}]
        else:
            # Default: all synths/channels, then each synth/channel
            selection_modes = [{'synth': 'all', 'ch': 'all'}]
            for synth_idx in range(num_synths):
                for ch in channels:
                    selection_modes.append({'synth': synth_idx, 'ch': ch})
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

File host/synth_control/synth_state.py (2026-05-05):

import os
import json
import logging
import copy
logger = logging.getLogger("NHP_Synth")

class SynthStateManager:
    def __init__(self, state_file, defaults_file):
        self.state_file = state_file
        self.defaults_file = defaults_file
        self.defaults = []
        self.synths = {}
        self.num_synths = 0
        self.synth_device_map = []
        self.selection_mode = None

        self.defaults = copy.deepcopy(self.load_defaults())
        loaded_state = self.load_state()
        if isinstance(loaded_state, dict):
            self.synths = loaded_state.get("synths", [])
        else:
            # load_state returned the defaults list directly
            self.synths = loaded_state

    def get_defaults(self, idx, key):
        if idx < len(self.defaults):
            return self.defaults[idx].get(key, self.defaults[0].get(key, 0.0))
        return self.defaults[0].get(key, 0.0)

    def _return_defaults(self):
        """Save and Return the default synths configuration."""
        self.save_defaults()
        return copy.deepcopy(self.defaults)

    def save_defaults(self):
        """Save the defaults to the defaults JSON file."""
        try:
            with open(self.defaults_file, 'w') as f:
                json.dump(self.defaults, f, indent=2)
        except Exception as e:
            logger.warning(f"Could not save defaults: {e}")

    def load_defaults(self):
        """Load defaults from the defaults JSON file, or use hardcoded defaults if file does not exist."""
        default_data = []
        for i in range(3):
            default_data.append({
                "auto_on": False,
                "enabled": { "a": False, "b": False },
                "amplitude_a": 96.0,
                "amplitude_b": 50.0,
                "frequency_a": 50.0,
                "frequency_b": 50.0,
                "phase_a": 0.0 if i == 0 else (120.0 if i == 1 else -120.0),
                "phase_b": 0.0 if i == 0 else (120.0 if i == 1 else -120.0),
                "harmonics_a": [],
                "harmonics_b": [
                    {"id": 0, "order": 5, "amplitude": 0, "phase": 0},
                    {"id": 1, "order": 7, "amplitude": 0, "phase": 0},
                    {"id": 2, "order": 11, "amplitude": 0, "phase": 0},
                    {"id": 3, "order": 13, "amplitude": 0, "phase": 0}
                ]
            })

        if not os.path.exists(self.defaults_file):
            self.defaults = default_data
            return self._return_defaults()
        try:
            with open(self.defaults_file, 'r') as f:
                data = json.load(f)

            self.defaults = copy.deepcopy(data)
            return self.defaults
        except Exception as e:
            logger.warning(f"Could not load defaults: {e}")
            self.defaults = default_data
            return self._return_defaults()

    def save_state(self):
        """Save the current synth/channel values to JSON file."""
        try:
            with open(self.state_file, 'w') as f:
                json.dump(
                    {
                        'num_synths': self.num_synths,
                        'synths': self.synths,
                        'synth_device_map': self.synth_device_map,
                    },
                    f,
                    indent=2,
                )
        except Exception as e:
            logger.warning(f"Could not save synth state: {e}")

    def load_state(self):
        """Load synth/channel values from JSON file, update internal state, and return the state dict."""
        if not os.path.exists(self.state_file):
            self.num_synths = len(self.defaults)
            self.synths = copy.deepcopy(self.defaults)
            self.save_state()
            return copy.deepcopy(self.defaults)
        try:
            with open(self.state_file, 'r') as f:
                state = json.load(f)
            if 'num_synths' not in state or 'synths' not in state:
                return copy.deepcopy(self.defaults)
            self.num_synths = state.get('num_synths', len(self.defaults))
            self.synths = state.get('synths', copy.deepcopy(self.defaults))
            synth_device_map = state.get('synth_device_map', [])
            self.synth_device_map = synth_device_map if isinstance(synth_device_map, list) else []
            self.num_synths = len(self.synths)
            # Ensure harmonics lists are lists
            for synth in self.synths:
                for key in ['harmonics_a', 'harmonics_b']:
                    if key not in synth or not isinstance(synth[key], list):
                        synth[key] = []
            return state
        except Exception as e:
            logger.warning(f"Could not load synth state: {e}")
            return copy.deepcopy(self.defaults)

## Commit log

2025-07-08 fix: correct command syntax for flashing multiple devices in README
2025-07-09 updated UART to unified command style (e.g. wh[a|b] instead of separate wha whb)
2025-07-22 Add NHP_Synth control interface and examples
    - Implemented a Python interface for controlling the ESP32 NHP_Synth dual-channel DDS synthesizer.
    - Created a development container configuration for easy setup.
    - Added README documentation with installation instructions and usage examples.
    - Developed example scripts for basic control and harmonic demonstrations.
    - Introduced a main control program using a rotary encoder for amplitude adjustments.
    - Included utilities for waveform generation and harmonic synthesis.
    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
2025-07-22 Enhance synthesizer connection handling and amplitude control for multiple devices
2025-07-22 Refactor main control logic for multi-encoder functionality and improve error handling for synthesizer connections
2025-07-23 Reset target amplitude values to zero and comment out unused timer control functions
    [main.c]
2025-07-23 Update flash_multiple.sh to build firmware before flashing multiple ESP32 devices
2025-07-24 Update frequency adjustment to allow 0.1Hz changes for all synthesizers
2025-07-24 Update flash_multiple.sh to dynamically find serial devices and resolve symlinks
2025-07-24 Optimize initialization, add color console output, and refactor code architecture
    - Speed up I2C encoder init with concurrent processing (50-65% faster)
    - Add comprehensive ANSI color-coded console output with timing metrics
    - Implement cached I2C scanning and reduced retry delays
    - Refactor into modular functions: initialize_system(), handle_encoder_buttons(), handle_encoder_rotation()
    - Add detailed initialization progress tracking and hardware status reporting
    - Improve USB device scanning with priority-based filtering
    - Enhance error handling and professional console formatting
2025-07-24 Multi-encoder control: default all-synth/channel mode, button for individual selection
    - Changed default behavior: all encoders (amplitude, frequency, phase, harmonics) affect all synths/channels simultaneously
    - Button press on encoder switches to individual synth/channel selection mode for that encoder
    - Cycling through individual synths/channels returns to "all" mode before wrapping
    - Added 60-second timeout: after inactivity, encoder reverts to "all" mode
    - Updated phase encoder: in "all" mode, only adjusts channel B on all synths (not both channels)
    - Updated reset logic and messages to reflect new phase behavior
    - Improved user feedback and usage instructions for new control scheme
    - R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
2025-07-25 Add SynthDiscovery class for USB device discovery and refactor main.py to utilize it; introduce Colors utility class for console output
2025-07-25 Refactor synthesizer control library
    - Renamed `uart_interface` to `synth_interface` and updated imports accordingly.
    - Added `synth_interface.py` to provide a UART interface for controlling the NHP_Synth synthesizer.
    - Introduced `system_initializer.py` to handle full system initialization, including I2C rotary encoder setup and synthesizer connections.
    - Updated `waveform_generator.py` to use the new `synth_interface`.
    - Enhanced the initialization process with detailed logging and error handling for better diagnostics.
    [synth_interface.py, system_initializer.py, waveform_generator.py]
2025-07-25 Remove init_single_encoder function to streamline encoder initialization process
2025-07-25 Add EncoderManager for handling encoder interactions and create physical test checklist
    - Introduced EncoderManager class to manage encoder button presses and rotations, including hold detection and state management for amplitude, frequency, phase, and harmonics.
    - Implemented functionality for resetting values, switching between individual and all synth modes, and handling harmonics updates.
    - Added a new physical test checklist to ensure hardware/software integration after code changes, covering various tests such as encoder detection, button presses, LED feedback, and error handling.
    [encoder_manager.py]
2025-07-25 converted print to common logging function
2025-07-25 Save synth state after resetting to defaults
    [encoder_manager.py]
2025-07-26 UART read commands added, new help text
2025-07-26 Change UART command task to run on core 1
    esp_timer always runs on core 0
2025-07-26 Increase UART command task stack size and adjust amplitude ramp step
2025-07-28 Complete overhaul of code structure and functionality
    - New classes and methods for Encoder management
    - Improved state management with deep copies
    - Enhanced Flask-SocketIO integration for real-time updates
    - Added threading for background tasks
    - Web dashboard using bootstrap and chartJS
    - Updated HTML and JavaScript for better user experienc
    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
2025-07-28 Add increment/decrement handlers for voltage, current, phase, and frequency; enhance UI controls
2025-07-28 Share selection mode state with EncoderManager and update web server to emit selection mode in synth state
2025-07-28 Implement selection mode timeout handling and reset inactivity timer in EncoderManager
    [encoder_manager.py]
2025-07-29 enhanced UI for voltage/current offcanvas. in process of creating harmonic offcanvas
2025-07-30 combined current and voltage offcanvas, selectable input groups
2025-07-30 fixed issue where defaults overwritten by current state
    [synth_state.py]
2025-07-31 power factor included in accordion header
2025-07-31 fixed issue where harmonic dial selection affected all synths instead of one.
    [encoder_manager.py]
2025-07-31 defaults are 0 voltage harmonics, 4x current harmonics
2025-07-31 fixed mutable defaults being updated unintentionally
    [synth_state.py]
2025-08-01 enabled phase rollover at +-180 for encoder rotation
2025-08-01 fixed individual phase wrapping of +-180
    [encoder_manager.py]
2025-08-02 fixed harmonic increment, voltage range to 250, global max V and I
    [synth_state.py]
2025-08-02 fixed state management issues with defaults overwriting
    [synth_state.py]
2025-08-03 feat: Add enable/disable functionality for synth channels
    - Updated firmware to include per-channel output enable/disable states and ramping.
    - Modified UART command handling to support reading and writing output enable states.
    - Enhanced host defaults to initialize enabled states for channels.
    - Implemented socket communication for enabling/disabling synth channels from the dashboard.
    - Added UI components for toggling channel enable states with visual feedback.
    - Updated command processing to handle new enable/disable commands.
    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
2025-08-04 better LED init
2025-08-04 feat: Add voltage, current, and horizontal scaling functionality for three-phase waveform chart
2025-08-04 feat: Implement settings management and enhance synth handlers
    - Added settings management endpoints in web_server.py for getting, saving, and resetting settings.
    - Introduced a settings.js module for handling settings initialization, updates, and UI interactions.
    - Updated synthHandlers.js to utilize dynamic max voltage and current settings from settings.js.
    - Enhanced error handling with a centralized errorHandler.js module.
    - Created app.js as the main application controller, managing socket connections and rendering.
    - Added debounce and throttle utilities in utils.js for performance optimization.
    - Improved LoadingSpinner UI component for better user feedback during data loading.
    - Refa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
    [test.py]
2025-08-10 Add initial configuration files for PCB interface
    [PCB_Interface.kicad_pcb, PCB_Interface.kicad_sch]
2025-10-27 Refactor increment buttons for improved styling and functionality; add time and voltage offset management
    - Updated incrementButtons component to enhance button sizes and styles for better user experience.
    - Introduced new functions for managing timebase, time offset, voltage offset, and current offset in state.js.
    - Removed deprecated horizontal scale handling and replaced it with timebase management.
    - Added functionality to step through voltage and current scales, ensuring they align with standard oscilloscope values.
    - Enhanced settings UI to conditionally display a close browser button in debug mode.
    - Updated state management to persist new settings and offsets in local storage.
2025-12-04 fix: Minimize glitches in DDS output by resetting accumulator at waveform peak
    [main.c]
2025-12-05 fix: Disable Bootstrap hover effects for buttons, nav links, and list items for consistency
2026-02-13 Update PCB production outputs
    [PCB_Interface.kicad_pcb, PCB_Interface.kicad_sch, bom.csv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]
2026-04-20 update to kicad10 libraries
    [3-phase-synth-model-Encoder-Plate.3mf, Drawing1.dwg, PCB_Interface.kicad_pcb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]
2026-05-01 feat(web-dashboard): unify touch-first numeric editing and remove legacy increment UI
    - Replace right-side increment stacks with modal-driven editing across Control and Harmonics tabs
    - Add field-aware touch modal behavior with configurable step profiles per input
    - Auto-apply step-button changes; keep manual keypad entry on explicit Apply
    - Add Reset in numeric modal to restore the active field to its default value
    - Enforce harmonic order constraints (odd integers only, bounded minimum/maximum) for both direct entry and step changes
    - Fix decrement behavior for harmonic order (for example 5 -> 3) and prevent values below minimum
    - Hide unusable controls per field (for example decimal key/f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
    [synth_interface.py]
2026-05-05 feat(synth-poller): enhance polling logic to track update and failure counts feat(system-initializer): improve synth reconnection logic and state synchronization refactor(synth-state): include synth_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
    [synth_discovery.py, synth_state.py, system_initializer.py]
